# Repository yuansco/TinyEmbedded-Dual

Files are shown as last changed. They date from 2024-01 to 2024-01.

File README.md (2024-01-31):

# TinyEmbedded-Dual
Low-cost Embedded Linux development board compatible with RISC-V D1s/F133 and ARM Cortex-A7 T113-S3 SoC.

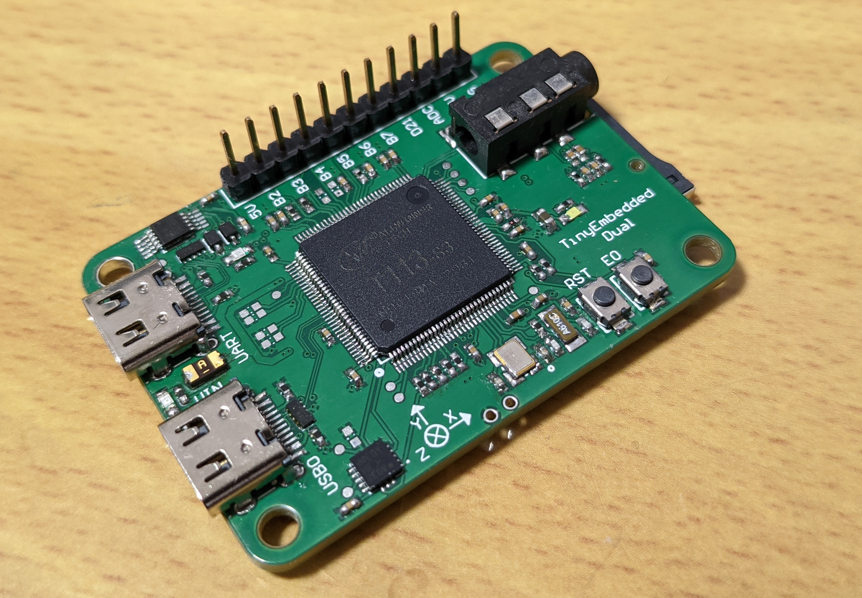
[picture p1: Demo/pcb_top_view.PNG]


## About the SoC
D1s/F133: Single-Core RISC-V 64 @ 1.0G with in package 64MB DDR2\
T113-S3: Dual-Core ARM Cortex-A7 @ 1.2 GHz with in package 128MB DDR3

## Feature
TinyEmbedded-Dual is a low-cost embedded Linux development board compatible with ARM Cortex-A7 T113-S3 and RISC-V D1s/F133 SoC. Here are some highlights of this board:

 * On-board USB-to-UART serial debug console.

 * On-board LIS3DH acceleration sensor.

 * On-board Realtek RTL8188FTV Wi-Fi Module.

 * One USB Type-C port support USB2.0.

 * Three indicator LEDs for power status, UART data transmission, and user-defined purposes.

 * Two buttons for reset and user-defined purposes.

 * One MicroSD slot for storing the boot image.

 * One Serial NOR Flash connected to SPI0.

 * One 3.5mm headphone jack for audio output.

## Hardware Design

#### Block Diagram

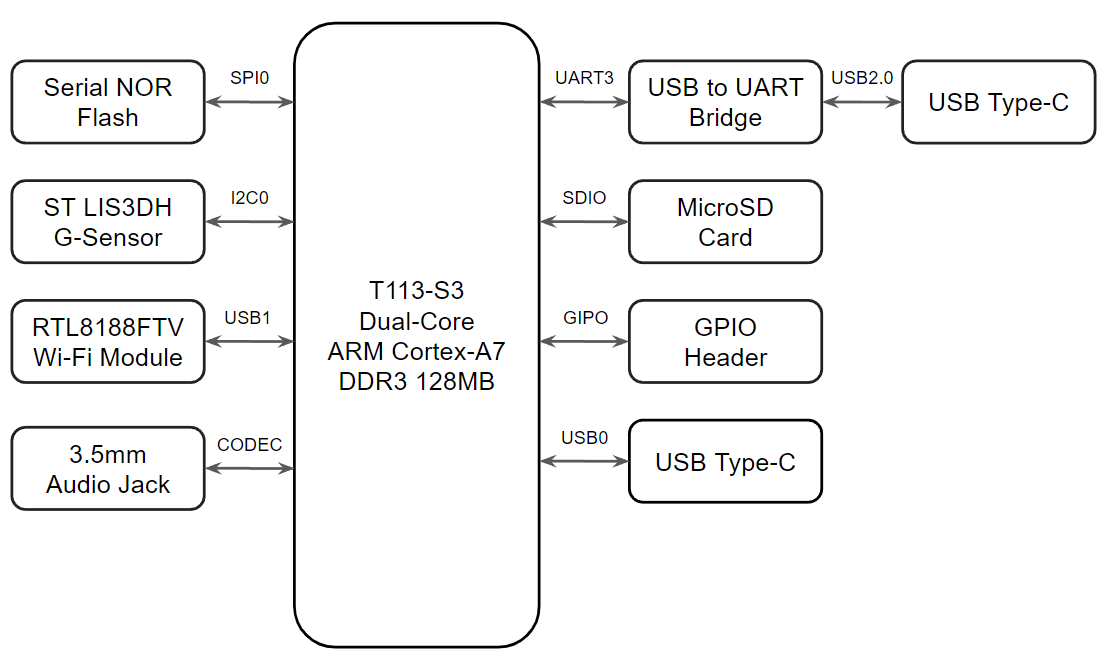
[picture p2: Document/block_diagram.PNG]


#### Power Tree

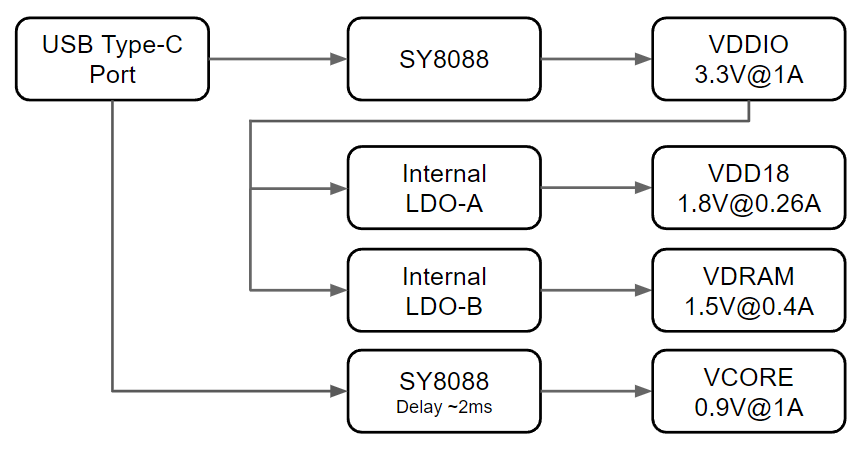
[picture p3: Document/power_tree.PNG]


#### 3D Simulation

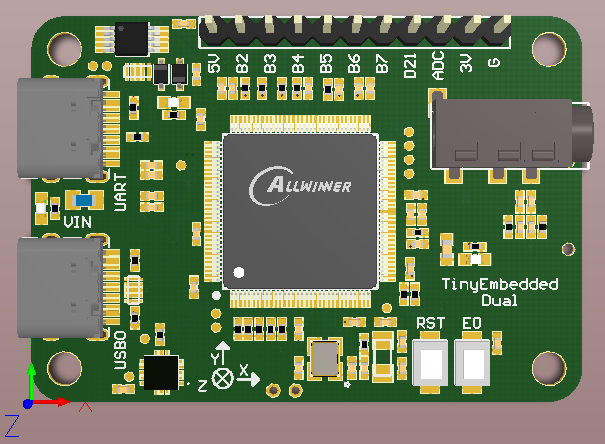
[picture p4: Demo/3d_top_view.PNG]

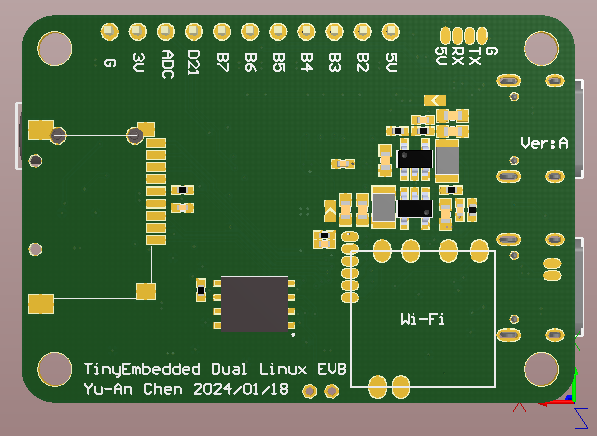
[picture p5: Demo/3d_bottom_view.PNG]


#### Top View

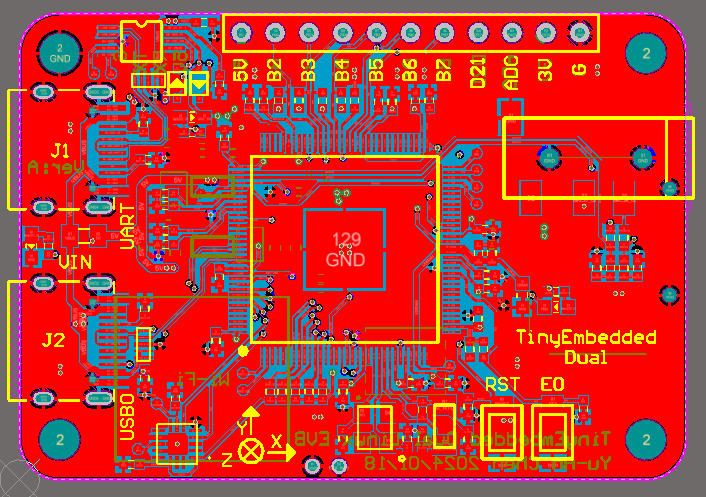
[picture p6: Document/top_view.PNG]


#### Download

Schematic: [PDF](https://github.com/yuansco/TinyEmbedded-Dual/blob/main/Document/TinyEmbedded_Dual_A.pdf)

BOM: [CSV](https://github.com/yuansco/TinyEmbedded-Dual/blob/main/Document/BOM.csv)

Image: [IMG](https://github.com/yuansco/TinyEmbedded-Dual/blob/main/Images/sdcard.img)

## Build an SD card image for booting TinyEmbedded-Dual

BSP is placed at [Buildroot-TinyEmbedded-Dual](https://github.com/yuansco/Buildroot-TinyEmbedded-Dual)

``` shell
# Install development tools
sudo apt install -y libssl-dev swig ncurses-dev flex bison

# Download TinyEmbedded-Dual BSP from Buildroot-TinyEmbedded-Dual
git clone https://github.com/yuansco/Buildroot-TinyEmbedded-Dual.git

# Apply defconfig
cd Buildroot-TinyEmbedded-Dual/buildroot
make tinyembedded_dual_t113_defconfig

# Build image
make 

# Flash image into your SD card. You need to replace /dev/sdx with the actual drive letter.
sudo dd if=./output/image/sdcard.img of=/dev/sdx bs=512 status=progress && sync
```

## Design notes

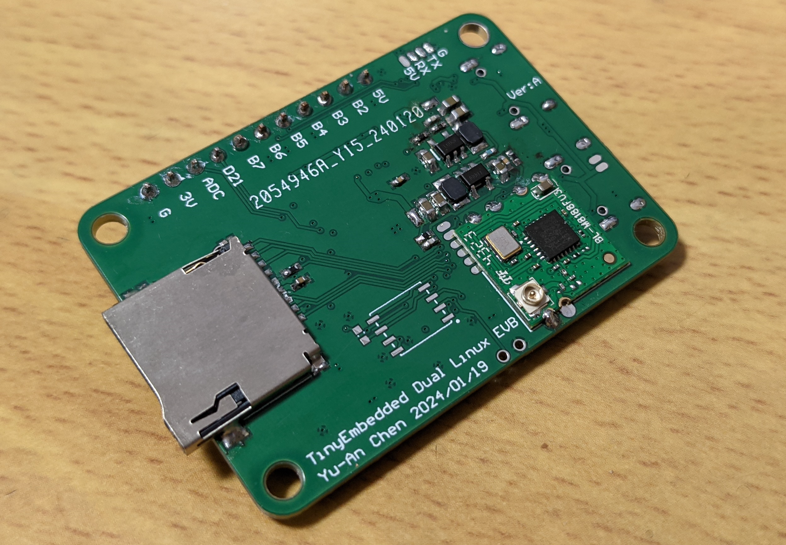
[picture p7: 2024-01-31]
Demo/pcb_bottom_view.PNG

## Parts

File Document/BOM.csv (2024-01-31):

Comment | Description | Designator | Footprint | LibRef | Quantity
SW_2P |  | Button, Reset | SW_2P_4 | SW_2P | 2
0.1uF,0402 |  | C1, C2, C3, C8, C9, C10, C11, C12, C17, C18, C19, C20, C21, C22, C23, C26, C27, C28, C29, C34, C35, C44, C45, C47, C48 | C0402 | Cap | 25
22uF,0603 |  | C4, C5, C13, C14 | C0603 | Cap | 4
10uF,0603 |  | C6, C15, C40 | C0603 | Cap | 3
10pF,0402 |  | C7, C16 | C0402 | Cap | 2
4.7uF,0402 |  | C24, C25, C36, C37 | C0402 | Cap | 4
*0.1uF,0402 |  | C30, C31, C32, C33 | C0402 | Cap | 4
12pF,0402 |  | C38, C39 | C0402 | Cap | 2
20pF,0402 |  | C42, C43 | C0402 | Cap | 2
1N5819 |  | D1, D2 | SOD-323 | Diode - Schottky | 2
5V,1.5A,0805 |  | F1 | F0805 | Fuse | 1
TypeC_F | Female SMD Connector | J1, J2 | Type-C_16P_F_0.5_DIP | Type-C_16P_F_0.5 | 2
Jump_2 |  | J3, J4 | Jp0603 | Jump_2 | 2
2.2uH |  | L1, L2 | IND_252010_SMD | Ind | 2
green,0603 |  | LD1 | LED0603 | Diode - LED | 1
blue,0603 |  | LD2 | LED0603 | Diode - LED | 1
white,0603 |  | LD3 | LED0603 | Diode - LED | 1
MicroSD |  | P1 | MicroSD | MicroSD | 1
Header_11 |  | P2 | Header_11 | Header_11 | 1
PJ-320D | Audio jack | P3 | PJ-320D | PJ-320D | 1
Header_4 |  | P4 | HEADER_4_SMD | Header_4 | 1
Header_2_2mm |  | P5 | Header_2_2mm | Header_2 | 1
Header_6_SMD |  | P6 | HEADER_6_SMD | Header_6 | 1
Header_2_SMD |  | P7 | HEADER_2_SMD | Header_2 | 1
5.1KΩ,0402 |  | R1, R2, R10, R11 | R0402 | Res | 4
4.7KΩ,0402 |  | R3, R4, R5, R6, R7, R8, R9, R19, R20, R21 | R0402 | Res | 10
680KΩ,0402 |  | R12, R26 | R0402 | Res | 2
150KΩ,0402 |  | R13, R15 | R0402 | Res | 2
75KΩ,0402 |  | R14 | R0402 | Res | 1
100KΩ,0402 |  | R16 | R0402 | Res | 1
*0Ω,0402 |  | R17 | R0402 | Res | 1
*4.7KΩ,0402 |  | R22, R23 | R0402 | Res | 2
33Ω,0402 |  | R24, R25, R27 | R0402 | Res | 3
75Ω,0402 |  | R28 | R0402 | Res | 1
4.7Ω,0402 |  | R29, R30 | R0402 | Res | 2
240Ω,0402,1% |  | R31 | R0402 | Res | 1
10KΩ,0402 |  | R34 | R0402 | Res | 1
TP |  | TP1, TP2, TP3, TP4, TP5, TP6, TP7, TP8, TP9, TP10, TP11, TP12 | TP | TP | 12
CH340E |  | U1 | MSOP-10 | CH340E | 1
TPD4E05U06 |  | U2, U3 | USON-10 | TPD4E05U06 | 2
SY8088 |  | U4, U11 | SOT-23-5p | SY8088 | 2
SPI Flash |  | U6 | WSON8 | SPI Flash | 1
USB Wi-Fi Module | BL-M8188FU3 RTL8188FTV | U8 | BL-M8188FU3 | USB Wi-Fi Module | 1
Allwinner T113-s3 |  | U9 | eLQFP128 | Allwinner T113-s3 | 1
LIS3DH |  | U10 | LGA-16 | LIS3DH | 1
32.768kHz |  | X1 | XTAL_3215_32.768KHz | XTAL | 1
24MHz |  | X2 | XTAL_SMD_3225 | XTAL | 1

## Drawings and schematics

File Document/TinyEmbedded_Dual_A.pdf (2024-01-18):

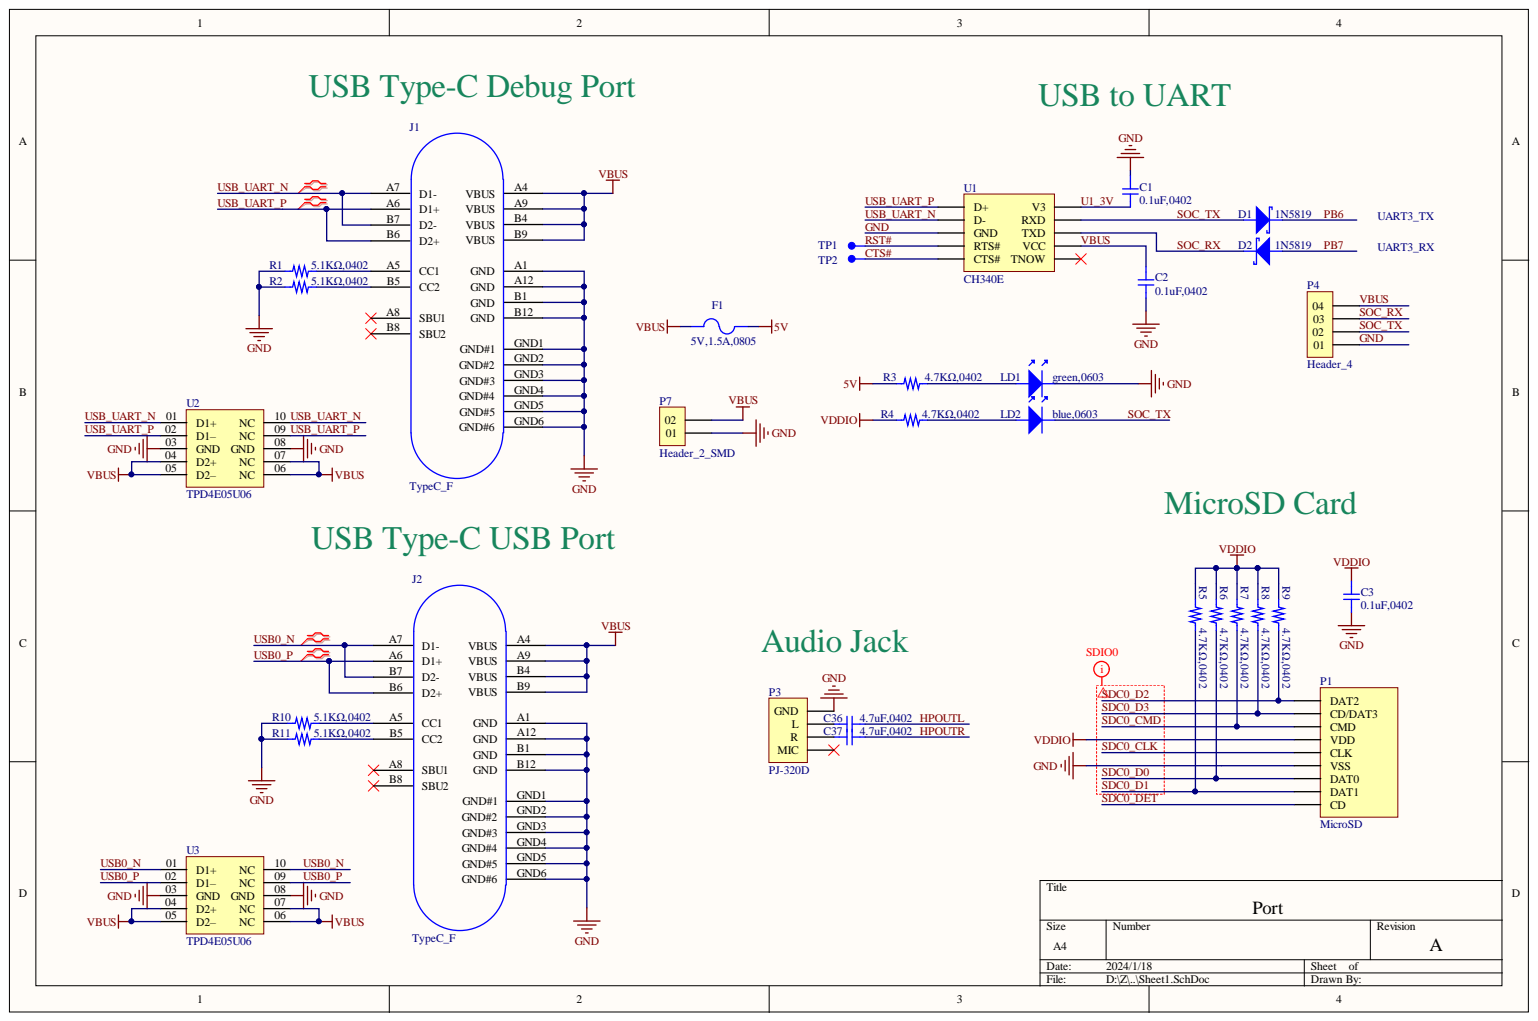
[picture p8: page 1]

USB Type-C Debug Port

USB Type-C USB Port

SDC0_CMD

SDC0_D0
SDC0_D1

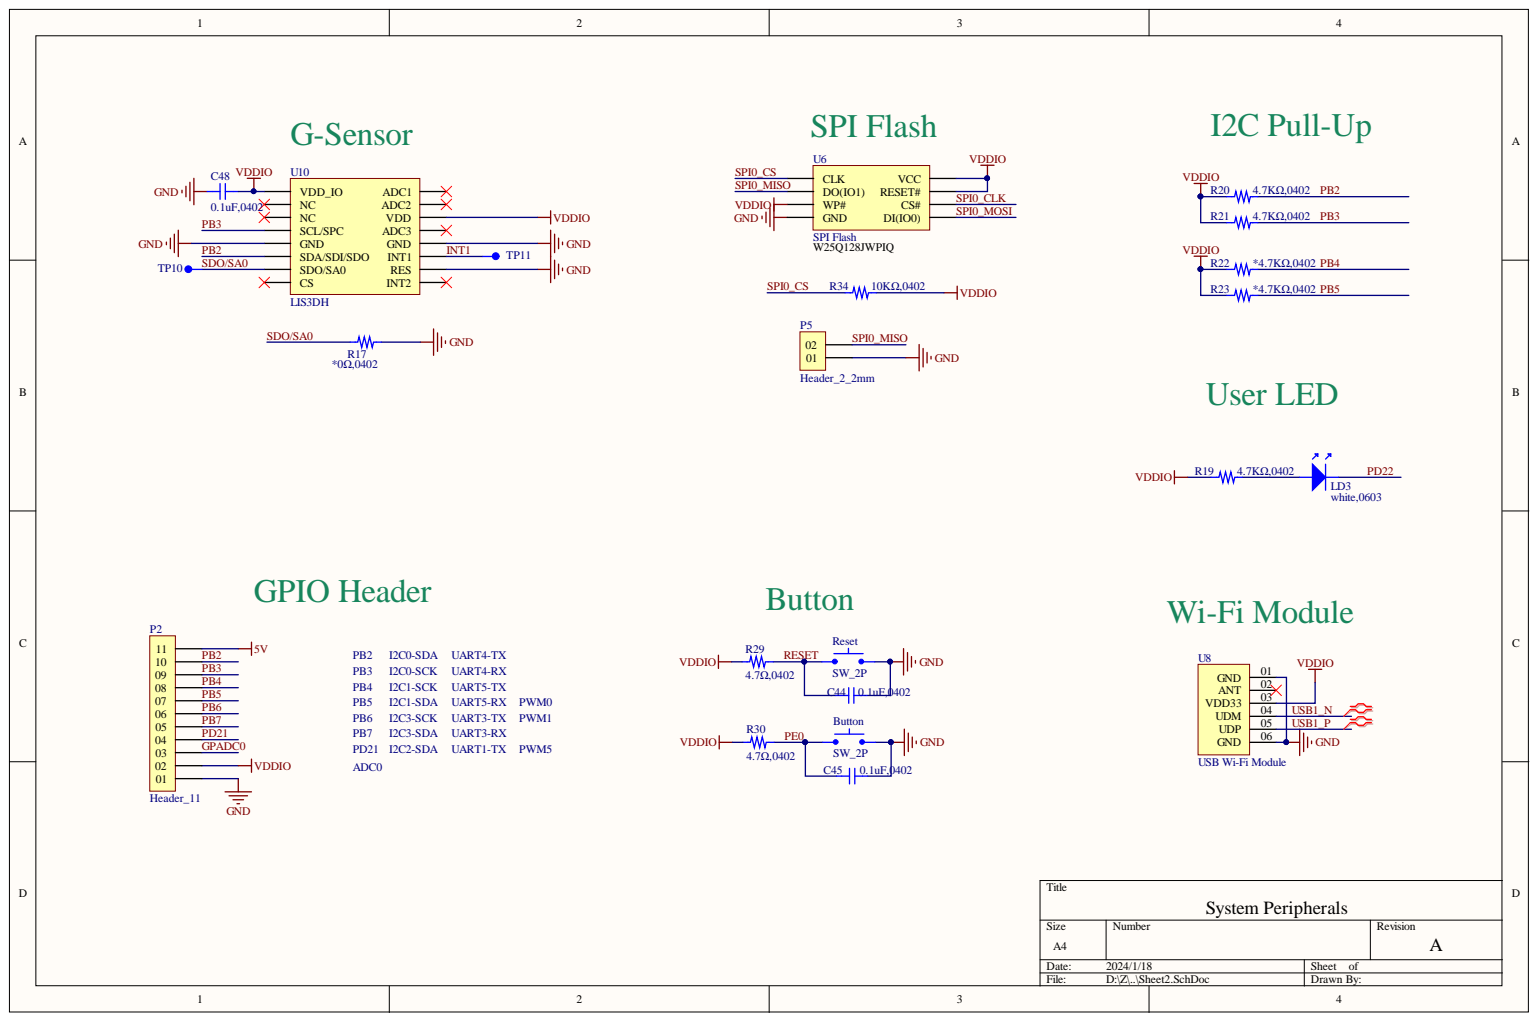
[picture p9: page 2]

USB Wi-Fi Module

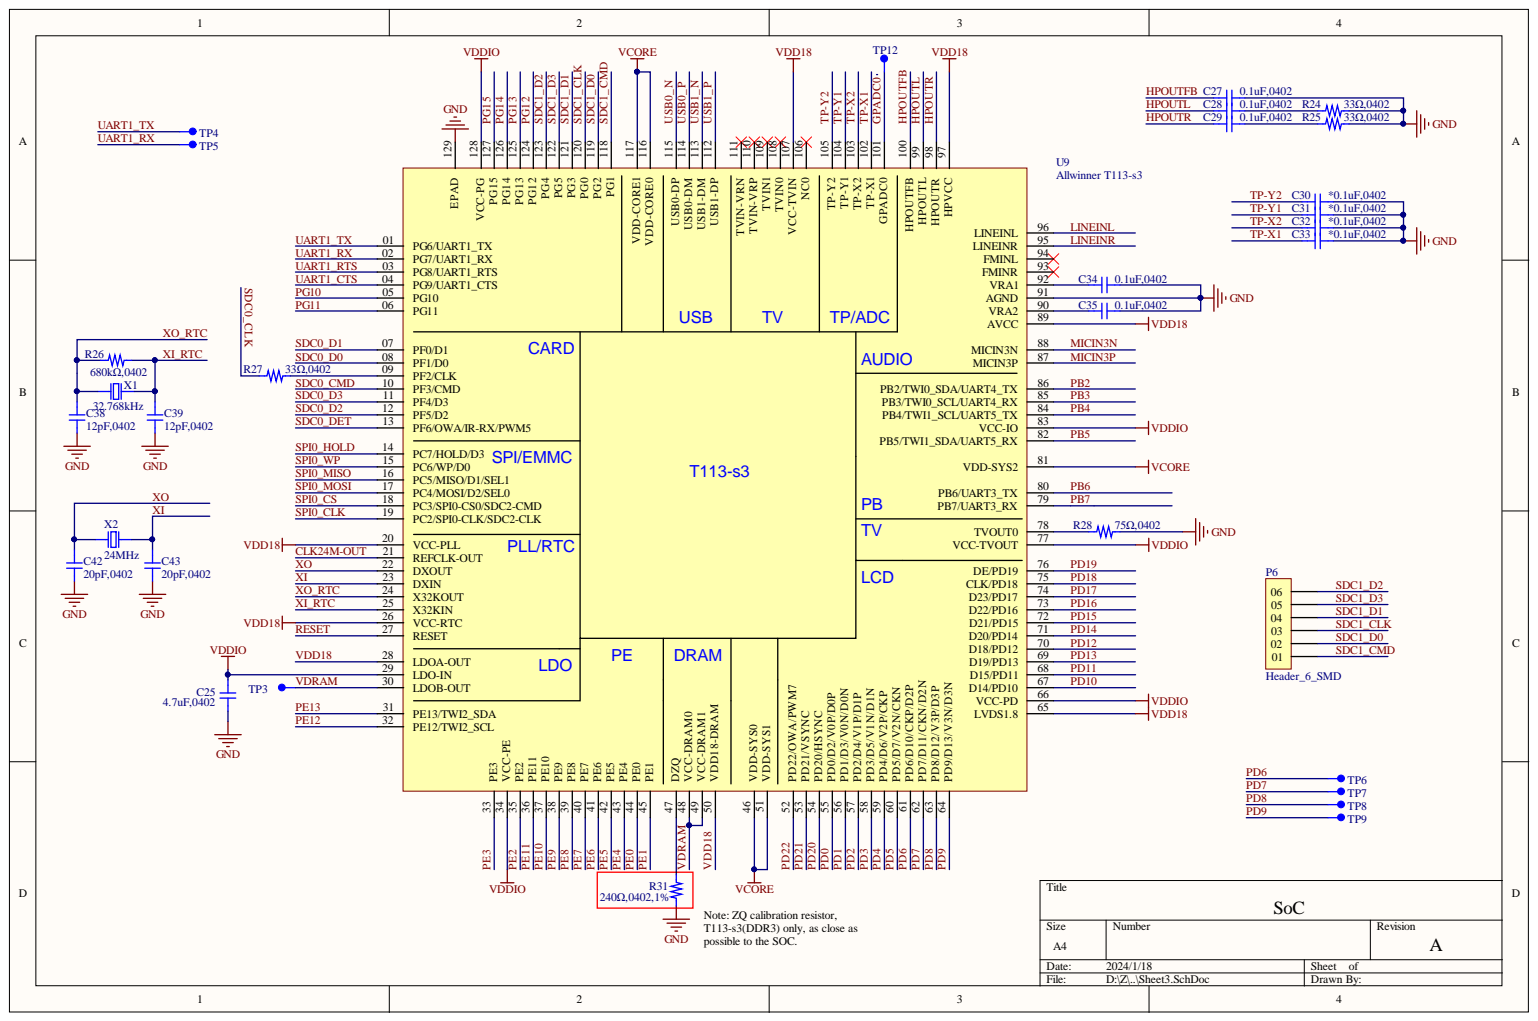
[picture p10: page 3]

USB1-DP 112 USB1-DM 113 USB0-DM 114 USB0-DP 115

NC0 106 VCC-TVIN 107 TVIN0 108 TVIN1 109 TVIN-VRP 110 TVIN-VRN 111

GPADC0 101 TP-X1 102 TP-X2 103 TP-Y1 104 TP-Y2 105

HPVCC 97 HPOUTR 98 HPOUTL 99 HPOUTFB 100

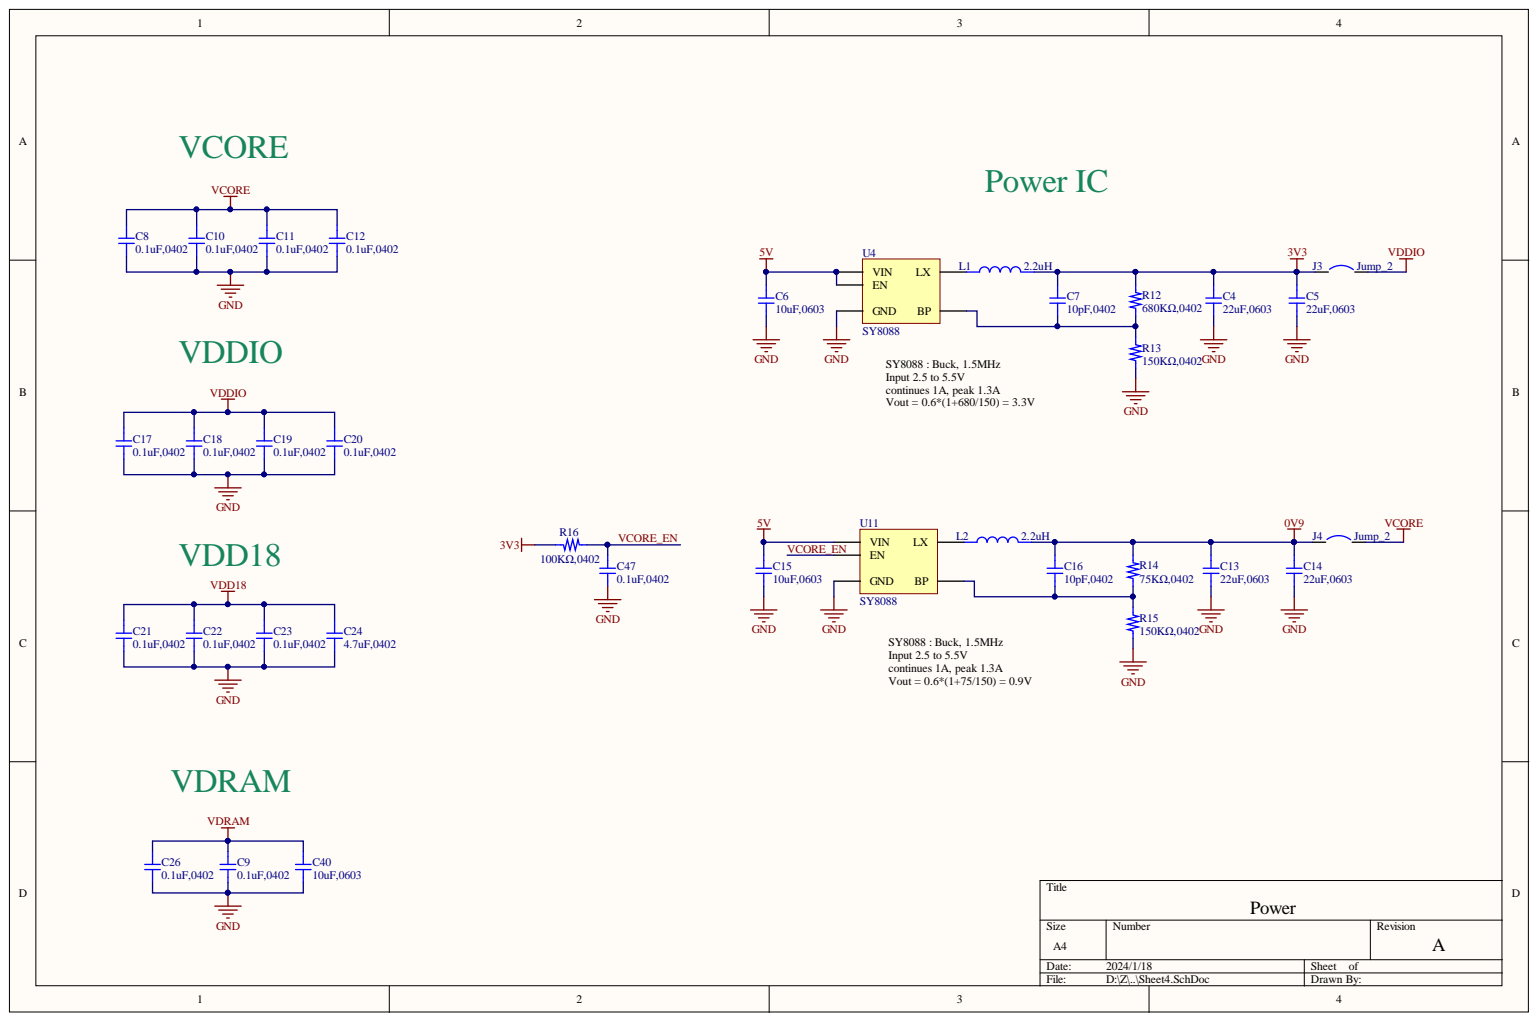
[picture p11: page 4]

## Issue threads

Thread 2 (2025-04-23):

No ALSA device for Headphone Jack Audio output

mozzwald, 2025-04-23:
Using the custom Buildroot, dmesg shows there is no audio device found:

```[    0.474909] ALSA device list:
[    0.474951]   No soundcards found.
```
Is the headphone jack confirmed working?

mozzwald, 2025-04-29:
I managed to make it work on newer mainline kernel with some patches and modified device tree. Sources available on my fork of [Buildroot-YuzukiSBC](https://github.com/mozzwald/Buildroot-YuzukiSBC) under the `lctech/lc-pi-t113` board definition and uses `allwinner-mainline` dtsi.

Posting in case you were interested or if someone else happens to be looking and trying to get audio / headphone out working on Allwinner T113.

Closed 2025-04-29.
